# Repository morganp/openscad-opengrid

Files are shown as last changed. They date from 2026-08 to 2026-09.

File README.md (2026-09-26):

# OpenSCAD openGrid

Reusable OpenSCAD library for building [openGrid](https://www.opengrid.world/) compatible
accessories. Pure OpenSCAD primitives, no external dependencies.

It gives you the snap connector, a test tile and a ready made bin, so any product you
design can be mounted to an openGrid board without re-deriving the interface geometry
each time.

```scad
include <opengrid.scad>

// a 2 x 2 patch of snaps, front faces flush with z = 0
opengrid_snap_grid(2, 2);

// your product sits at z >= 0
translate([-28, -28, 0]) cube([56, 56, 3]);
```

---

## Coordinate convention

`z = 0` is the **front face of the board**. Product geometry lives at `z >= 0`,
snap geometry at `z <= 0`. Every internal dimension is quoted as a *depth* `d`
measured into the board, so a point at depth `d` sits at `z = -d`.

This means you can drop `opengrid_snaps(...)` straight into a union with a
backplate whose bottom face is on `z = 0` and it just works.

---

## Modules

### `opengrid_snap(lite, nubs, corner_clearance)`

One snap plug.

| Parameter | Default | Description |
|---|---|---|
| `lite` | `false` | `true` gives a 3.4 mm snap for a 4.0 mm Lite board |
| `nubs` | `true` | Fit the flexing retaining nubs. `false` gives a plain locating plug |
| `corner_clearance` | `0` | Shrinks the corner capture cone. `0` is the nominal conformal fit; try `0.05` to `0.1` if your printer runs fat |

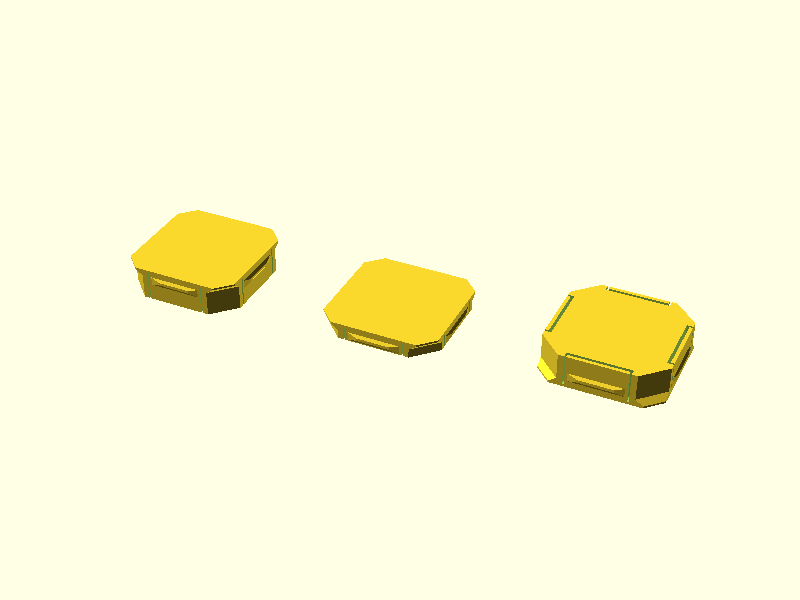
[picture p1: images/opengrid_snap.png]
Snap


*Left: full snap. Centre: lite snap. Right: full snap flipped to show the relief slots behind each nub.*

### `opengrid_snaps(positions, lite, nubs, corner_clearance)`

Snaps at a list of `[x, y]` centres. Use this when you want snaps only at
particular cells, for example the top and bottom rows of a tall backplate.

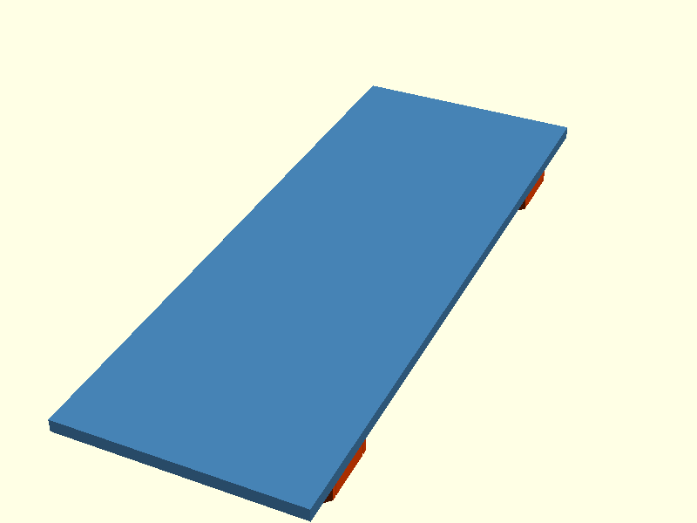
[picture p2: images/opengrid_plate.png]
Plate


### `opengrid_snap_grid(cols, rows, lite, nubs, corner_clearance)`

A snap in every cell of a `cols` x `rows` patch, centred on the origin.

### `opengrid_tile(cols, rows, lite)`

A board patch for test fitting, front face on `z = 0`.

This carries the **cell profile only**. It is deliberately not a drop-in
replacement for a printed openGrid board: there are no edge connector cutouts,
screw bosses or tile-to-tile features. Print a single cell of it to check your
snap tolerances before committing to a big part.

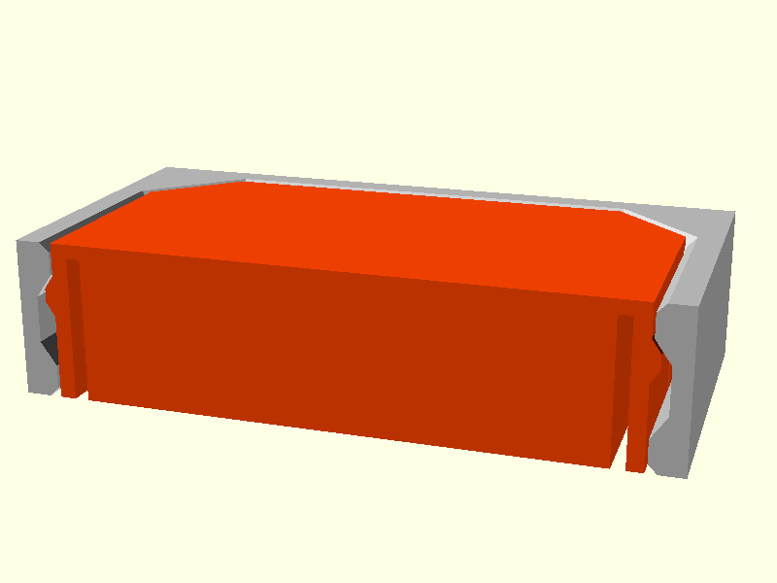
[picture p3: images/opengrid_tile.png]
Tile section


*A snap seated in a tile, sectioned through the middle. The tile section (grey) shows the face chamfer, the 25.0 mm land and the 26.4 mm groove. The snap section (orange) shows a nub sitting in that groove and the relief slots that let it flex.*

### `opengrid_cell_void(lite)`

The negative space of one cell opening. Difference this out of your own slab if
you want to make boards rather than accessories.

### `opengrid_bin(cols, depth, height, ...)`

An open top bin with snaps on its back wall. Width is set in grid columns, so
bins always land on the grid.

```scad
include <opengrid.scad>

opengrid_bin(cols = 3, depth = 40, height = 56, divisions_x = 2, snap_rows = "ends");
```

| Parameter | Default | Description |
|---|---|---|
| `cols` | `3` | Grid columns covered. Outer width is `og_bin_width(cols)` |
| `depth` | `40` | How far the bin stands out from the board |
| `height` | `28` | Grid height, top edge on a grid line. At least 28; use a multiple of 28 to stack bins |
| `wall` | `2` | Side, front and back wall thickness |
| `floor` | `2` | Floor thickness |
| `divisions_x` | `1` | Equal compartments across the width |
| `divisions_y` | `1` | Equal compartments front to back |
| `divider` | `1.6` | Divider thickness |
| `chamfer` | `3` | Outer 45 degree chamfer on the front edges |
| `inner_chamfer` | `2` | Inner chamfer along the floor and inside corners |
| `clearance` | `0.5` | Total gap shared with the neighbouring bins, `0.25` each side |
| `snap_spacing` | `2` | Largest column step between snaps. `2` is every other cell |
| `snap_rows` | `"top"` | `"top"`, `"ends"` (top and bottom full rows) or `"all"` |
| `snap_cols` | `undef` | Explicit list of snap columns, overrides `snap_spacing` |
| `lite`, `nubs`, `corner_clearance` | | Passed through to `opengrid_snap()` |

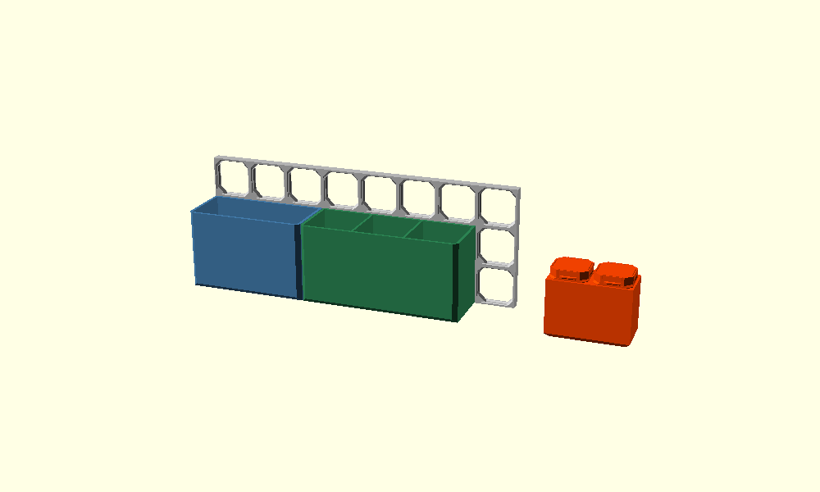
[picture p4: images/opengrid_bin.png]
Bin


*Left: a 3 column bin and a 4 column bin with three compartments, side by side on
an 8 x 3 board. Right: a 2 column bin in its print orientation, snaps up.*

**Coordinates.** Library convention: the back of the bin is on `z = 0` and it
stands out in `+z`. The left grid line is `x = 0` and `y` runs up the board with
the top grid line at `y = height`. Put the origin on a board corner and every
snap is in a cell.

**Snap pattern.** Snaps go in both end columns and are spread at most
`snap_spacing` apart, mirror symmetric. An even width has no centre column, so it
takes an even number of snaps.

| cols | Snap columns (`snap_spacing = 2`) |
|---|---|
| 1 | 0 |
| 2 | 0, 1 |
| 3 | 0, 2 |
| 4 | 0, 3 |
| 5 | 0, 2, 4 |
| 6 | 0, 2, 3, 5 |
| 7 | 0, 2, 4, 6 |
| 8 | 0, 2, 5, 7 |

**Grid fit.** Every snap centre sits at `14 + 28 * n` from the bin's left grid
line, for odd and even widths alike. So bins of any mix of widths butt together
along a row with only the `clearance` gap between them, and all their snaps land
in cells. Pick the width with `og_cols_for_inner()`:

| cols | Outer width | Inner width (`wall = 2`) |
|---|---|---|
| 1 | 27.5 | 23.5 |
| 2 | 55.5 | 51.5 |
| 3 | 83.5 | 79.5 |
| 4 | 111.5 | 107.5 |
| 5 | 139.5 | 135.5 |
| 6 | 167.5 | 163.5 |
| 7 | 195.5 | 191.5 |
| 8 | 223.5 | 219.5 |

With dividers, each compartment is `(inner - (divisions_x - 1) * divider) / divisions_x`.

**Printing.** Print the bin **front face down, snaps up**
(`mirror([0, 0, 1]) opengrid_bin(...)`). The snaps then print exactly as
designed, with every overhang at 45 degrees or less. The only overhang left is the
inside of the back wall, which bridges between the side walls and any
`divisions_x` dividers. The bridge sag is on the inside of the bin, so it does not
touch the snap face. Keep each bridge under about 60 mm, by adding dividers if
needed, or tune your slicer's bridge settings.

Printing the bin upright (floor on the bed) leaves a flat 6.8 mm cantilever under
every snap, including the retaining nubs. That weakens the fit, so it is not
recommended.

## Functions

| Function | Returns |
|---|---|
| `og_thickness(lite)` | Board thickness, 6.8 or 4.0 |
| `og_snap_depth(lite)` | How far a snap reaches in, 6.8 or 3.4 |
| `og_span(n)` | Outer size of `n` cells, `n * 28` |
| `og_grid_positions(cols, rows)` | `[x, y]` cell centres, patch centred on origin |
| `og_bin_width(cols, clearance)` | Outer width of a bin covering `cols` cells, `cols * 28 - clearance` |
| `og_cols_for(mm, clearance)` | Fewest columns for an outer width of at least `mm` |
| `og_cols_for_inner(mm, wall, clearance)` | Fewest columns for an inner width of at least `mm` |
| `og_bin_rows(height)` | Full grid rows a bin of this height covers |
| `og_bin_snap_cols(cols, spacing)` | Snap column indices used by `opengrid_bin()` |
| `og_bin_snap_positions(cols, height, spacing, snap_rows, snap_cols)` | `[x, y]` snap centres in bin coordinates |

---

## Placing snaps on a backplate

Snap centres must land on the 28 mm grid, and each snap needs 12.4 mm of
clearance around its centre, so keep centres at least 14 mm from a plate edge.

For a plate of height `H` carrying two rows:

```scad
rows_apart = floor((H - 28) / OG_PITCH) * OG_PITCH;
y0         = (H - rows_apart) / 2;
```

`examples/opengrid_plate_example.scad` does exactly this for a 56 x 152 mm plate:
it lands on 112 mm between rows with 20 mm margins.

---

## The interface, in numbers

All dimensions in mm. Depth is measured from the board's front face.

**Grid**

| | |
|---|---|
| Cell pitch | 28.0 |
| Full board thickness | 6.8 |
| Lite board thickness | 4.0 |
| Lite snap depth | 3.4 |

**Cell opening.** The opening is an **octagon** with sharp 45 degree corners, not
a rounded square. There are no fillets anywhere in the profile.

| Depth | Across flats | Corner distance from centre | Feature |
|---|---|---|---|
| 0.0 | 25.8 | 15.629 | Board face |
| 0.4 | 25.0 | 15.229 | End of the 45 degree face chamfer |
| 1.4 | 25.0 | 14.229 | End of the land, end of the corner lead-in |
| 2.4 | 26.4 | 14.229 | Groove full width, via a 35 degree ramp |
| to rear | 26.4 | 14.229 | Groove |

"Corner distance" is the perpendicular distance from the cell centre to the 45
degree corner face. It comes from the openGrid corner block: a 2.6 mm square set
back 4.2 mm along the diagonal, so `28/sqrt(2) - (4.2/sqrt(2) + 2.6)` = 14.229.

A **Full** board is symmetric front to back, so a full snap engages from either
face and two lite snaps fit back to back in one cell. A **Lite** board is the
front 4.0 mm of that profile, cut off flat at the rear with no rear chamfer.

**Snap**

| | |
|---|---|
| Body across flats | 24.8, giving 0.10 clearance per side on the land |
| Body corner distance | 14.129 |
| Front plate | 0.4 thick, corner distance 15.229, flush with the board face |
| Corner capture cone | 45 degrees from depth 0.4 to 1.5, nests in the cell's corner lead-in |
| Nub protrusion | 0.4 beyond the body face, tip at 25.6 across flats |
| Nub depth range | 1.4 to 3.2, with a 0.6 ramp at each end |
| Nub width | 11.0 at the root, 7.1 at the tip |
| Flexing skin | 0.7 thick, freed by a 0.6 slot and two 0.4 slits, anchored over the front 0.6 |

At rest the nub tip clears the groove. Pulling the snap out moves the tip onto
the 35 degree groove ramp after about 0.2 mm of travel, which is what holds it
in. Insertion deflects each nub about 0.3 mm.

---

## Printing

Following the [openGrid printing guide](https://www.opengrid.world/guides/printing/):

- 0.4 mm nozzle, 0.2 mm layer height
- PLA or PETG, not flexibles
- At least 3 perimeters if the part will carry weight
- Infill 15% or more
- Do not use a draft or fast profile, it will ruin the snap tolerances

Print accessories with the **front face of the product on the bed**, so the snaps
point upward. Every snap overhang is then 45 degrees or shallower and no support
is needed.

If your snaps are too tight, raise `corner_clearance` to 0.05 before you start
scaling the whole model.

**Test before you commit.** Print `examples/opengrid_tile_example.scad` cut down
to a single cell, plus one bare snap, and check the fit by hand.

---

## Verifying a design

The snap and the cell profile are built from the same constants, so they can be
checked against each other geometrically. Export the intersection of a snap and a
tile: if the snap fits, the result has zero volume.

```scad
intersection() {
    translate([-14, -14, 0]) opengrid_tile(1, 1);
    opengrid_snap();
}
```

---

## File structure

```
opengrid.scad                        -- library, include this
examples/
  opengrid_snap_example.scad         -- snaps on their own
  opengrid_tile_example.scad         -- a snap seated in a tile, sectioned
  opengrid_plate_example.scad        -- snaps on a tall two-row backplate
  opengrid_bin_example.scad          -- odd and even width bins side by side on a board
images/                              -- rendered previews
```

## Installing

```sh
git clone https://github.com/morganp/openscad-opengrid.git \
  ~/Documents/OpenSCAD/libraries/opengrid
```

Then `include <opengrid/opengrid.scad>` from anywhere.

---

## Credit and licensing

**openGrid** is a wall and desk mounting system by **David D**, published under
**CC BY 4.0**:

- <https://www.printables.com/model/1214361-opengrid-walldesk-mounting-framework-and-ecosystem>
- <https://www.opengrid.world/>

This library is an **original implementation** of the published interface
dimensions, written from the documented geometry. It contains no code from any
other openGrid project. It is openGrid *compatible*; it is not official and is
not endorsed by the openGrid project.

The following projects were read as references while confirming the interface
numbers, and are worth a look if you want a different feature set:

- [AndyLevesque/QuackWorks](https://github.com/AndyLevesque/QuackWorks) (CC BY-NC-SA 4.0)
- [mitufy/opengrid-projects](https://github.com/mitufy/opengrid-projects) (CC BY 4.0 / CC BY-SA 4.0)
- [jp-embedded/opengrid](https://github.com/jp-embedded/opengrid) (GPL-3.0)

`opengrid_bin()` is inspired by two community projects. It is a fresh
implementation on this library's own snaps and contains none of their code:

- **Customizable openGrid Bins** by **Mikey Ward** ([@wookiee](https://makerworld.com/en/@wookiee)),
  CC BY-SA 4.0: <https://makerworld.com/en/models/1813759-customizable-opengrid-bins>.
  The bin shape, chamfered lip and divider options follow this design.
- **openGrid Tile Generator** by **BlackjackDuck (Andy)**
  ([MakerWorld](https://makerworld.com/en/@BlackjackDuck), part of QuackWorks above),
  CC BY-NC-SA 4.0. Use it to print the boards these bins mount on.

This library is MIT licensed. See [LICENSE](LICENSE).

## Versioning

[Semantic Versioning 2.0.0](https://semver.org). See [CHANGELOG.md](CHANGELOG.md).

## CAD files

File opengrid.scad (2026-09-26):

/*
 * opengrid.scad -- openGrid compatible snap connectors and test tiles
 *
 * Pure OpenSCAD primitives, no external dependencies.
 *
 * Public modules:
 *   opengrid_snap(lite)                  -- one snap plug, front face on z = 0, body in -z
 *   opengrid_snaps(positions, lite)      -- snaps at a list of [x, y] centres
 *   opengrid_snap_grid(cols, rows, lite) -- snaps at every cell of a cols x rows patch
 *   opengrid_tile(cols, rows, lite)      -- test-fit board tile, front face on z = 0
 *   opengrid_cell_void(lite)             -- the negative space of one cell opening
 *   opengrid_bin(cols, depth, height)    -- open top bin with snaps on its back wall
 *
 * Public functions:
 *   og_thickness(lite)                   -- board thickness for the variant
 *   og_snap_depth(lite)                  -- how far a snap reaches into the board
 *   og_grid_positions(cols, rows)        -- [x, y] cell centres, patch centred on origin
 *   og_span(n)                           -- outer size of n cells
 *   og_bin_width(cols, clearance)        -- outer width of a bin covering cols cells
 *   og_cols_for(mm), og_cols_for_inner(mm, wall)
 *                                        -- fewest cols for an outer or inner width
 *   og_bin_rows(height)                  -- full grid rows a bin height covers
 *   og_bin_snap_positions(cols, height)  -- [x, y] snap centres on a bin back
 *
 * Coordinate convention: z = 0 is the front face of the board. Product geometry
 * lives at z >= 0, snap geometry at z <= 0. Depth d below is measured from the
 * front face, so a point at depth d sits at z = -d.
 *
 * openGrid is a CC BY 4.0 system by David D:
 *   https://www.printables.com/model/1214361
 * This library is an original implementation of the published interface
 * dimensions. It is openGrid compatible, not official.
 */

$fn = $fn > 0 ? $fn : 64;

// ---------------------------------------------------------------------------
// Interface constants
// ---------------------------------------------------------------------------

OG_PITCH            = 28;    // cell to cell spacing, both axes
OG_FULL_THICKNESS   = 6.8;   // full board
OG_LITE_THICKNESS   = 4.0;   // lite board
OG_LITE_SNAP_DEPTH  = 3.4;   // a lite snap uses 3.4 of the 4.0 lite board

// Cell opening, measured across flats
OG_CELL_FACE_FLAT   = 25.8;  // at the board face
OG_CELL_LAND_FLAT   = 25.0;  // the land the snap body is sized against
OG_CELL_GROOVE_FLAT = 26.4;  // the retaining groove

// Cell opening, depths from the face
OG_CELL_CHAMFER_D   = 0.4;   // face chamfer, 45 degrees
OG_CELL_LAND_END_D  = 1.4;   // land runs from OG_CELL_CHAMFER_D to here
OG_CELL_GROOVE_D    = 2.4;   // groove is full width from here inward

// The opening is an octagon. These are perpendicular distances from the cell
// centre to the 45 degree corner faces. Derived from the openGrid corner block:
// a 2.6 mm square set back 4.2 mm along the diagonal from the cell corner.
OG_CORNER_OFFSET    = 4.2 / sqrt(2) + 2.6;                   // 5.569849
OG_CELL_CORNER      = OG_PITCH / sqrt(2) - OG_CORNER_OFFSET; // 14.229142
OG_CELL_CORNER_LEAD = 1.4;                                   // 45 degree corner lead in
OG_CELL_FACE_CORNER = OG_CELL_CORNER + OG_CELL_CORNER_LEAD;  // 15.629142

// Snap body
OG_SNAP_FLAT        = 24.8;                       // 0.1 clearance per side on the land
OG_SNAP_CORNER      = OG_CELL_CORNER - 0.1;       // 14.129142
OG_SNAP_FACE_D      = 0.4;                        // front plate thickness
OG_SNAP_CAPTURE_D   = 1.5;                        // corner capture taper ends here
// The front plate corners sit where the cell corner lead in has reached 0.4 mm
// of depth, so the capture cone nests conformally.
OG_SNAP_FACE_CORNER = OG_CELL_FACE_CORNER - OG_SNAP_FACE_D;  // 15.229142

// Snap retaining nubs, one per flat face
OG_NUB_PROTRUSION   = 0.4;   // beyond OG_SNAP_FLAT / 2
OG_NUB_TOP_D        = 1.4;   // depth of the nub's leading edge
OG_NUB_BOT_D        = 3.2;   // depth of the nub's trailing edge
OG_NUB_WEDGE        = 0.6;   // length of each ramp, so the tip band is 0.6 long
OG_NUB_ROOT_W       = 11.0;  // width where the nub meets the body
OG_NUB_TIP_W        = 7.1;   // width at full protrusion

// Spring reliefs that turn the outer skin behind each nub into a cantilever
OG_SKIN             = 0.7;   // flexing wall thickness
OG_RELIEF_SLOT_W    = 0.6;   // gap behind the skin
OG_RELIEF_SLOT_LEN  = 12.4;  // how wide the relieved region is
OG_RELIEF_SLIT_W    = 0.4;   // slits down each side of the tab
OG_RELIEF_ANCHOR_D  = 0.6;   // solid depth at the front that anchors the tab

EPS = 0.01;

// ---------------------------------------------------------------------------
// Functions
// ---------------------------------------------------------------------------

function og_thickness(lite = false) =
    lite ? OG_LITE_THICKNESS : OG_FULL_THICKNESS;

function og_snap_depth(lite = false) =
    lite ? OG_LITE_SNAP_DEPTH : OG_FULL_THICKNESS;

function og_span(n) = n * OG_PITCH;

function og_grid_positions(cols = 1, rows = 1) =
    [ for (r = [0 : rows - 1], c = [0 : cols - 1])
        [ (c - (cols - 1) / 2) * OG_PITCH,
          (r - (rows - 1) / 2) * OG_PITCH ] ];

// ---------------------------------------------------------------------------
// Profile helpers
// ---------------------------------------------------------------------------

/*
 * og_octagon -- the openGrid cross section
 *
 *   flat   -- size across the four straight faces
 *   corner -- perpendicular distance from centre to the 45 degree corner faces
 *
 * A square rotated 45 degrees with side 2 * corner has its faces exactly
 * `corner` from the centre, so intersecting the two squares gives the octagon.
 */
module og_octagon(flat, corner) {
    intersection() {
        square([flat, flat], center = true);
        rotate(45) square([corner * 2, corner * 2], center = true);
    }
}

/*
 * og_loft -- straight taper between two octagon profiles
 *
 * Depths are measured from the front face, so d0 must be less than d1 and the
 * result occupies z = -d0 down to z = -d1.
 *
 * Built as the intersection of two independently tapered square prisms, one
 * straight and one turned 45 degrees. At every height the cross section is the
 * intersection of the two interpolated squares, which is exactly the octagon
 * for that depth. No epsilon fudge, so sections butt together cleanly.
 */
module og_loft(d0, flat0, corner0, d1, flat1, corner1) {
    h = d1 - d0;
    translate([0, 0, -d1])
    intersection() {
        linear_extrude(height = h, scale = flat0 / flat1)
            square([flat1, flat1], center = true);
        rotate([0, 0, 45])
            linear_extrude(height = h, scale = corner0 / corner1)
                square([corner1 * 2, corner1 * 2], center = true);
    }
}

// ---------------------------------------------------------------------------
// Board
// ---------------------------------------------------------------------------

/*
 * og_cell_half -- the front half of a cell opening, front face at z = 0
 *
 * Runs from the face down to `to_d`. Flats: 25.8 at the face, 45 degree chamfer
 * to 25.0, a 1.0 mm land, then a 35 degree ramp out to the 26.4 groove.
 * Corners: a 45 degree lead in over the first 1.4 mm, constant after that.
 */
module og_cell_half(to_d) {
    face_c = OG_CELL_FACE_CORNER;
    ch_c   = face_c - OG_CELL_CHAMFER_D;

    og_loft(0, OG_CELL_FACE_FLAT, face_c,
            OG_CELL_CHAMFER_D, OG_CELL_LAND_FLAT, ch_c);

    og_loft(OG_CELL_CHAMFER_D, OG_CELL_LAND_FLAT, ch_c,
            OG_CELL_LAND_END_D, OG_CELL_LAND_FLAT, OG_CELL_CORNER);

    og_loft(OG_CELL_LAND_END_D, OG_CELL_LAND_FLAT, OG_CELL_CORNER,
            OG_CELL_GROOVE_D, OG_CELL_GROOVE_FLAT, OG_CELL_CORNER);

    if (to_d > OG_CELL_GROOVE_D)
        og_loft(OG_CELL_GROOVE_D, OG_CELL_GROOVE_FLAT, OG_CELL_CORNER,
                to_d, OG_CELL_GROOVE_FLAT, OG_CELL_CORNER);
}

/*
 * opengrid_cell_void -- negative space of one cell opening
 *
 * Front face at z = 0, running to z = -thickness. A full board is symmetric
 * front to back, so a full snap can be fitted from either side. A lite board
 * is the front 4.0 mm of that profile, cut off flat at the rear.
 */
module opengrid_cell_void(lite = false) {
    t = og_thickness(lite);

    if (lite) {
        og_cell_half(t);
    } else {
        og_cell_half(t / 2 + EPS);
        translate([0, 0, -t]) mirror([0, 0, 1]) og_cell_half(t / 2 + EPS);
    }
}
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

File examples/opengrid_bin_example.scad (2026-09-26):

// opengrid_bin_example.scad -- bins hanging on a board, and one laid out for printing
include <../opengrid.scad>

// Mounted view. The board is stood upright so y points up the wall.
// A 3 column bin (odd) and a 4 column bin (even) sit side by side. Both
// widths put every snap in a cell, so any mix of widths packs flush along a row.
rotate([90, 0, 0]) {
    color("silver") opengrid_tile(8, 3);

    color("steelblue")
        opengrid_bin(cols = 3, depth = 40, height = 56, snap_rows = "ends");

    color("seagreen") translate([og_span(3), 0, 0])
        opengrid_bin(cols = 4, depth = 40, height = 56, divisions_x = 3,
                     snap_rows = "ends");
}

// Print orientation: front face on the bed, snaps pointing up. The snaps need
// no support; the back wall bridges between the side walls and dividers.
color("orangered") translate([og_span(8) + 30, -40, 40]) mirror([0, 0, 1])
    opengrid_bin(cols = 2, depth = 40, height = 28, divisions_y = 2);

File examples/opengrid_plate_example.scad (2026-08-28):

// opengrid_plate_example.scad -- typical use: a product backplate that carries
// snaps only at its top and bottom rows
include <../opengrid.scad>

plate_w = og_span(2);   // 56
plate_h = 152;
plate_t = 3;

// snap centres must land on the 28 mm grid and keep 14 mm clear of the edges
rows_apart = floor((plate_h - 28) / OG_PITCH) * OG_PITCH;   // 112
y0 = (plate_h - rows_apart) / 2;                            // 20

positions = [ for (x = [-1, 1], y = [y0, plate_h - y0])
                [x * OG_PITCH / 2, y - plate_h / 2] ];

color("steelblue")
    translate([-plate_w / 2, -plate_h / 2, 0]) cube([plate_w, plate_h, plate_t]);
color("orangered") opengrid_snaps(positions);

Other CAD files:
examples/opengrid_snap_example.scad
examples/opengrid_tile_example.scad

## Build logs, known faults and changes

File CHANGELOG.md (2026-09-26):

# Changelog

All notable changes to this project are documented here. This project uses
[Semantic Versioning 2.0.0](https://semver.org).

## 1.1.0 - 2026-09-26

### Added

- `opengrid_bin()`: open top bin with snaps on its back wall, sized in grid
  columns, with optional dividers in both directions.
- Snap centres land on board cells for odd and even column counts alike, so bins
  of mixed widths pack flush along a row.
- Sizing helpers: `og_bin_width()`, `og_cols_for()`, `og_cols_for_inner()`,
  `og_bin_rows()`, `og_bin_snap_cols()`, `og_bin_snap_positions()`.
- `examples/opengrid_bin_example.scad` and `images/opengrid_bin.png`.
- Print orientation guidance for bins: front face down, snaps up.

## 1.0.0 - 2026-08-28

### Added

- `opengrid_snap()`, `opengrid_snaps()`, `opengrid_snap_grid()`,
  `opengrid_tile()` and `opengrid_cell_void()`, full and lite variants.

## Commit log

2026-08-28 feat: openGrid compatible snap connector library
    Original OpenSCAD implementation of the openGrid mounting interface, so
    accessory projects can share one definition of the connector instead of
    re-deriving it.
    Provides opengrid_snap(), opengrid_snaps(), opengrid_snap_grid() and a
    test-fit opengrid_tile(), with full and lite board variants.
    Geometry is built from the published interface dimensions: 28 mm pitch,
    octagonal cell opening (25.8 face / 25.0 land / 26.4 groove) with sharp
    45 degree corners, and a 24.8 mm snap body with 0.4 mm flexing nubs at
    depth 1.4 to 3.2.
    Sections are lofted as the intersection of two independently tapered
    square prisms rather than hulled slabs, so profiles ar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
    [opengrid.scad, opengrid_plate_example.scad, opengrid_snap_example.scad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]
2026-09-26 feat: add opengrid_bin and grid sizing helpers
    Adds an open top bin that hangs on the board, sized in grid columns,
    with optional dividers across the width and front to back.
    Snap centres sit at 14 + 28 * n from the bin's left grid line for any
    column count, so odd and even width bins pack flush along a row and
    every snap lands in a cell. Snaps use both end columns, spread at most
    snap_spacing apart, mirror symmetric.
    Helpers og_bin_width, og_cols_for, og_cols_for_inner, og_bin_rows,
    og_bin_snap_cols and og_bin_snap_positions cover sizing a bin to a
    required inner width.
    Recommended print orientation is front face down, snaps up: snaps keep
    every overhang at 45 degrees or less and the onl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
    [opengrid.scad, opengrid_bin_example.scad]
